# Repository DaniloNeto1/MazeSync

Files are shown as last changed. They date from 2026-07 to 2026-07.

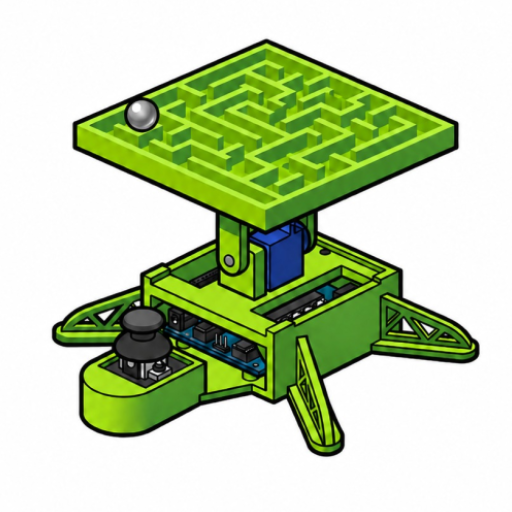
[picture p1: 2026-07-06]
app/src/main/app-playstore.png

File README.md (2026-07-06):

# 🕹️ MazeSync

Controle interativo em tempo real de um labirinto mecânico físico utilizando comunicação via rede sem fio entre um microcontrolador e um smartphone. 

Este repositório adota a arquitetura de **Monorepo**, contendo tanto o código embarcado (Hardware) quanto o aplicativo móvel (Software).

## 📐 Arquitetura do Sistema

O sistema é dividido em duas frentes que se comunicam via protocolo **UDP** em uma rede local (Access Point gerado pelo hardware), garantindo baixíssima latência (aprox. 15ms) para movimentação fluida.

1. **📱 App Android (Kotlin):** Lê os sensores de gravidade do smartphone utilizando a *Sensor API* nativa do Android SDK e atira pacotes UDP em uma *Thread* paralela (Background) contendo as coordenadas $X$ e $Y$.
2. **⚙️ Hardware (C++ / ESP32):** Microcontrolador recebe os pacotes de rede e traduz os ângulos em modulação PWM para controlar os micro-servos do labirinto. Também inclui lógica de interpolação para controle manual via Joystick analógico.

---

## 🛠️ Tecnologias Utilizadas

* **Linguagens:** Kotlin (App), C/C++ (Hardware)
* **Ambientes:** Android Studio, VS Code (PlatformIO)
* **Protocolo de Rede:** UDP (User Datagram Protocol) via Wi-Fi `802.11 b/g/n`
* **Hardware:** ESP32, Servo Motores (SG90), Módulo Joystick Analógico

---

## 🚀 HOW TO: Como executar o projeto

### Pré-requisitos
* **Android Studio** instalado para compilar o app.
* **VS Code** com a extensão **PlatformIO** para gravar o ESP32.

### Passo 1: Configurando o Hardware (ESP32)
1. Abra a pasta `Hardware-ESP32` no VS Code (PlatformIO).
2. Conecte o ESP32 ao computador via cabo USB.
3. Clique no ícone de **Upload** (seta para a direita) na barra inferior do PlatformIO para compilar e gravar o firmware na placa.
4. Após gravado, o ESP32 iniciará automaticamente uma rede Wi-Fi (Access Point).

### Passo 2: Configurando o Software (App Android)
1. Abra a pasta raiz do projeto Android no **Android Studio**.
2. Conecte seu smartphone ao computador via cabo USB (com o modo de depuração USB ativado) ou use um emulador.
3. Clique em **Run 'app'** (ícone de Play verde) na barra superior.
4. O aplicativo será instalado e aberto no seu dispositivo.

### Passo 3: Sincronizando (O Jogo)
1. No seu smartphone, vá nas configurações de Wi-Fi e conecte-se à rede gerada pelo ESP32 (ex: `MazeSync_AP`).
2. Abra o aplicativo MazeSync.
3. Incline o celular! O aplicativo fará a leitura da gravidade com um fator de ganho calibrado ($K = 7.0$) e os motores do labirinto responderão em tempo real respeitando a janela mecânica segura de 60° a 120°.

---

## 👨‍💻 Autor

**Danilo Pietrobon Neto** Engenharia de Computação - UTFPR
**Monica P. O. Mackert**  Engenharia de Computação - UTFPR

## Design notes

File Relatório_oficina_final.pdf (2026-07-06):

TRABALHO DE OFICINA DE INTEGRAÇÃO

## MazeSync: labirinto físico automatizado

DANILO PIETROBON NETO¹
MONICA PAULA OLIVEIRA MACKERT

2

PATO BRANCO - PR
JULHO/2026

1 Graduando em Engenharia de Computação pela UTFPR-PB.
email: danilopietrobon@alunos.utfpr.edu.br
2 | Graduanda | em | Engenharia | de | Computação | pela | UTFPR-PB.
email: monicamackert @alunos.utfpr.edu.br

RESUMO

Este artigo apresenta o desenvolvimento de um protótipo funcional de um labirinto físico automatizado controlado bilateralmente por meio de hardware dedicado e um aplicativo móvel personalizado. O sistema substitui as abordagens tradicionais baseadas em microcontroladores de arquitetura restrita pelo chip ESP32 de alto desempenho, programado no ecossistema PlatformIO. A inclinação do tabuleiro do labirinto é controlada por dois servo motores configurados nos eixos X e Y. O controle do sistema ocorre por meio de uma lógica de prioridades que integra um joystick analógico físico e um aplicativo Android desenvolvido em Kotlin no Android Studio. A comunicação sem fio é estabelecida configurando o ESP32 como Access Point (AP), recebendo dados de telemetria baseados nos sensores de gravidade e giroscópio do smartphone por meio do protocolo de transporte UDP (User Datagram Protocol). Os resultados obtidos demonstraram baixa latência e alta precisão na manipulação dinâmica e mecânica do tabuleiro, validando a integração de software móvel com sistemas embarcados de baixo custo.

Palavras-chave: ESP32. Android Studio. Kotlin. UDP. Giroscópio. Servomotores.

### 1. INTRODUÇÃO

O estudo e a implementação de sistemas ciber-físicos, o qual combina processamento computacional, redes de comunicação e processos mecânicos, representam um pilar essencial na formação em Engenharia de Computação. Jogos físicos clássicos de habilidade motora, como o labirinto de inclinação mecânica com esferas metálicas, oferecem um excelente modelo experimental para a aplicação desses conceitos. Tradicionalmente controlados de forma manual por manivelas, esses sistemas podem ser automatizados através de servomotores acionados por microcontroladores.

Contudo, muitos projetos acadêmicos utilizam plataformas limitadas em processamento e sem conectividade nativa, restringindo a experiência de controle a botões ou joysticks com fio. Este projeto propõe a modernização desse cenário através do desenvolvimento de um labirinto inteligente com controle bilateral: físico, via joystick analógico acoplado diretamente à base; e sem fio, utilizando os sensores de movimento internos de um dispositivo móvel.

O sistema foi reprojetado utilizando o SoC (System on Chip) ESP32, aproveitando sua capacidade de conectividade sem fio integrada e temporizadores robustos. A interface móvel foi desenvolvida em ambiente de produção moderno com a linguagem Kotlin. O objetivo central é analisar a viabilidade técnica e a eficiência de uma comunicação ponto a ponto de baixa latência em tempo real para controle mecânico de precisão, oferecendo uma alternativa robusta e de baixo custo para o ensino prático de sistemas integrados.

### 2. TRABALHOS RELACIONADOS

- Sistemas Embarcados com Controle por Fio: Diversas abordagens acadêmicas utilizam microcontroladores como o Arduino Uno acoplados a joysticks de potenciômetros bidirecionais (ex: KY023). Embora eficazes no controle mecânico básico, sofrem restrições severas de mobilidade espacial devido ao cabeamento físico estrutural.

- Aplicações de Telemetria com Protocolo TCP: Projetos que utilizam comunicação sem fio integrada via Wi-Fi frequentemente adotam o protocolo de transporte TCP para o envio de comandos de aplicativos móveis. Apesar de garantir a entrega confiável dos pacotes, a sobrecarga de controle (handshake, retransmissões) gera picos de latência que prejudicam o controle em tempo real de sistemas que necessitam de respostas instantâneas, como o equilíbrio de esferas.
- Sistemas Móveis de Captura Inercial: O uso de sensores internos de smartphones (como acelerômetros e giroscópios) é amplamente documentado em jogos digitais mobile. A adaptação desses dados brutos de hardware para a conversão mecânica de inclinação em dispositivos físicos externos de automação representa um campo de estudo dinâmico e em constante evolução no âmbito da Internet das Coisas (IoT).

### 3. REFERENCIAL TEÓRICO

Integração de Hardware e Software

A convergência entre hardware e software permite a criação de sistemas interativos onde informações do mundo físico são convertidas para dados digitais. No contexto do ecossistema MazeSync, essa integração possibilita a leitura de sensores inerciais e analógicos e a sua tradução em comandos angulares mecânicos.

Protocolo de Transporte UDP

Diferente do protocolo TCP, o UDP opera em modo não-orientado à conexão. Isso significa que os datagramas são enviados diretamente ao destino sem a necessidade de verificação de recebimento ou ordenação de pacotes. Essa ausência de overhead torna o UDP a escolha ideal para sistemas de controle contínuo, onde pacotes antigos perdem a validade e a taxa de atualização instantânea é prioritária.

Sensores Inerciais de Gravidade e Movimento

Dispositivos móveis modernos possuem IMUs (Units de Medição Inercial) integradas. O sensor de gravidade (Sensor. TYPE_GRAVITY) realiza uma filtragem de software dos componentes do acelerômetro, isolando a força da gravidade nos três eixos cartesianos (x, y, z). Ao inclinar o celular, os valores gerados representam a aceleração em m/s² aplicada sobre cada eixo coordenado.

### 4. METODOLOGIA

Arquitetura Estrutural do Hardware
O protótipo consiste em uma estrutura física composta por uma base estável, um braço mecânico de suporte articulado em dois eixos e um tabuleiro superior dotado de um labirinto impresso em 3D. A movimentação física é executada por dois servo motores micro (SG90) alimentados por modulação por largura de pulso (PWM) gerada de forma independente através dos timers nativos do ESP32 via biblioteca ESP32Servo. O código de controle foi estruturado com base em uma máquina de estados de prioridades bem definidas rodando em um loop cíclico de 15 ms.

Prioridade 1 - Botão SW: O pino digital PIN_JOY_SW configurado com resistor pull-up interno monitora continuamente o botão do joystick. Se o botão for pressionado (LOW), o sistema executa a função resetarCentro(), forçando os servos a ficarem nivelados.

Prioridade 2 - Controle Físico Dinâmico: Se o joystick for retirado de sua zona morta (JOY_DEADZONE = 150), os sinais analógicos das portas PIN_JOY_X e PIN_JOY_Y são convertidos pelo ADC interno (0 a 4095). É calculado um

incremento angular dinâmico (variando de 0. 2 a 1. 5 graus), que é somado à posição atual dos servos. Enquanto o joystick estiver em movimento, os comandos sem fio são ignorados.

Prioridade 3 - Controle Móvel: Caso o joystick permaneça estático no centro, o ESP32 passa a processar as requisições de rede. Ele varre o buffer do socket de escuta UDP (udpPort = 12345). Se houver pacotes, os dados textuais são processados via função sscanf() para extrair os novos ângulos absolutos enviados pelo aplicativo Android.

Para garantir a integridade dos servos e das articulações impressas, todos os ângulos calculados passam obrigatoriamente pela função limitarAngulo(), que restringe fisicamente o curso de movimento entre a faixa de segurança de 58 a 118 graus.

Para mitigar desvios de montagem, foram criadas as variáveis SERVO_CENTER_X e SERVO_CENTER_Y, permitindo calibrar de forma independente o nivelamento de cada eixo em 88 graus para compensar os desalinhamentos físicos da estrutura.

Conectividade de Rede e Configuração do Access Point (AP)

Para garantir independência de redes locais e roteadores externos, o ESP32 é inicializado programaticamente no modo Access Point (AP) de forma isolada. O firmware define uma rede local Wi-Fi restrita com o SSID "MazeSync − ESP32" protegida por criptografia WPA2. O dispositivo embarcado define para si um IP estático fixo (192.168.4.1) e inicializa o servidor UDP na porta 12345, aguardando pacotes de dados originados do cliente conectado.

Desenvolvimento do Aplicativo Android

O aplicativo de controle móvel foi desenvolvido em ambiente nativo Android Studio utilizando a linguagem Kotlin com suporte à arquitetura moderna de telas cheias (enableEdgeToEdge). O fluxo de execução do software consiste na seguinte rotina:

Gerenciamento de Sensores: Durante o ciclo de atividade em primeiro plano

(onResume), o aplicativo registra um ouvinte (SensorEventListener) associado ao Sensor. TYPE_GRAVITY configurado com taxa de amostragem

otimizada para jogos eletrônicos (SENSOR_DELAY_GAME).

Processamento de Dados Inerciais: No evento onSensorCℎanged, os valores brutos de gravidade dos eixos X e Y são capturados. O aplicativo aplica um fator de escala linear (7. 0) adicionado ao centro trigonométrico de

90 graus: anguloX = 90(gx * 7, 0).

Os resultados finais são sanitizados utilizando a função de extensão . coerceIn(60, 120), garantindo a conformidade lógica com os limites mecânicos do hardware.

Transmissão Assíncrona via Rede: Para evitar o congelamento da interface gráfica (UI Tℎread) do usuário, sempre que uma alteração angular é detectada, uma linha de execução paralela (tℎread) é gerada. O payload é estruturado como uma String otimizada no formato simples "X,Y", convertida em um array de bytes UTF-8 e encapsulada em um pacote DatagramPacket disparado via DatagramSocket diretamente para o endereço IP do destino (192.168.4.1:12345).

### 5. RESULTADOS E DISCUSSÕES

Resultados do Sistema Embarcado e Hardware

O ecossistema montado com o PlatformIO garantiu a portabilidade exata e estabilidade das diretivas de compilação do chip esp32doit-devkit-v1. O controle do pulso PWM via hardware utilizando os timers internos do ESP32 eliminou por completo trepidações mecânicas comuns causadas por ruídos de amostragem. A filtragem de software baseada em zonas mortas no código do ADC preveniu movimentos falsos indesejados originados do joystick físico.

Desempenho do Aplicativo Móvel e Comunicação UDP

O sensor de gravidade implementado no Android Studio mostrou-se extremamente responsivo a mudanças sutis de orientação física do smartphone. A interface gráfica do aplicativo atualizou de forma contínua e assíncrona as coordenadas processadas, exibindo na tela os ângulos dinâmicos de transmissão de forma clara.

O uso do protocolo UDP sem conexão eliminou os atrasos severos observados em sistemas semelhantes operando em protocolos orientados a fluxo. A String estruturada separada por vírgulas representou uma carga útil de rede insignificante, permitindo que o processamento interno do ESP32 via sscanf realizasse a extração das coordenadas em microsegundos, resultando em um controle mecânico altamente intuitivo e em tempo real.

Prioridade de Controle

Os testes práticos comprovaram a integridade e eficácia da arquitetura modular de prioridades. Quando o usuário inclinava o celular (transmitindo pacotes contínuos por Wi-Fi) e realizava um toque manual no joystick, o firmware interrompia o processamento da rede imediatamente para obedecer ao periférico físico, retornando ao controle sem fio no exato momento em que o joystick era solto. O acionamento do botão físico de reset interrompeu o fluxo de execução global de forma segura, garantindo o retorno da esfera metálica ao centro do tabuleiro sempre que necessário.

### 5.1 Demonstração Prática e Resultados Visuais

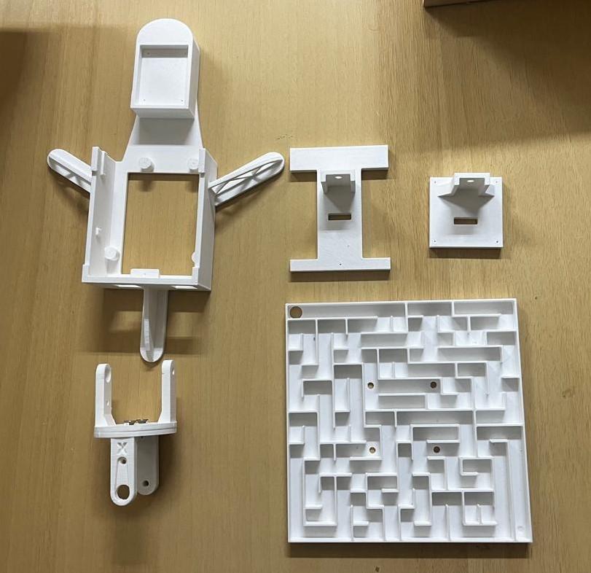
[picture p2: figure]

Figura 1: Estrutura física 3D. Fonte: Autoria própria.

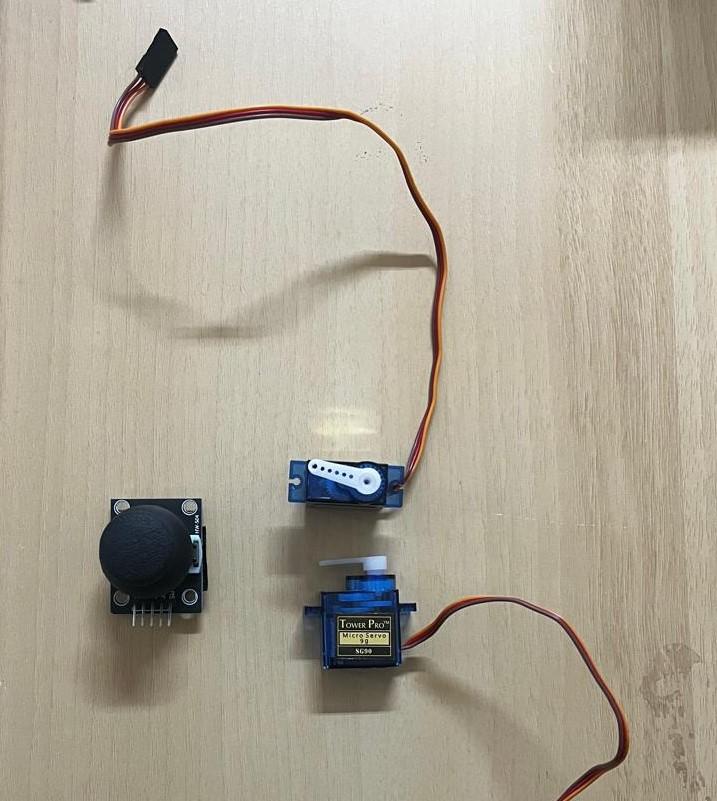
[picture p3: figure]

Figura 2: Servo motor SG90 e Joystick KY023 Fonte: Autoria própria.

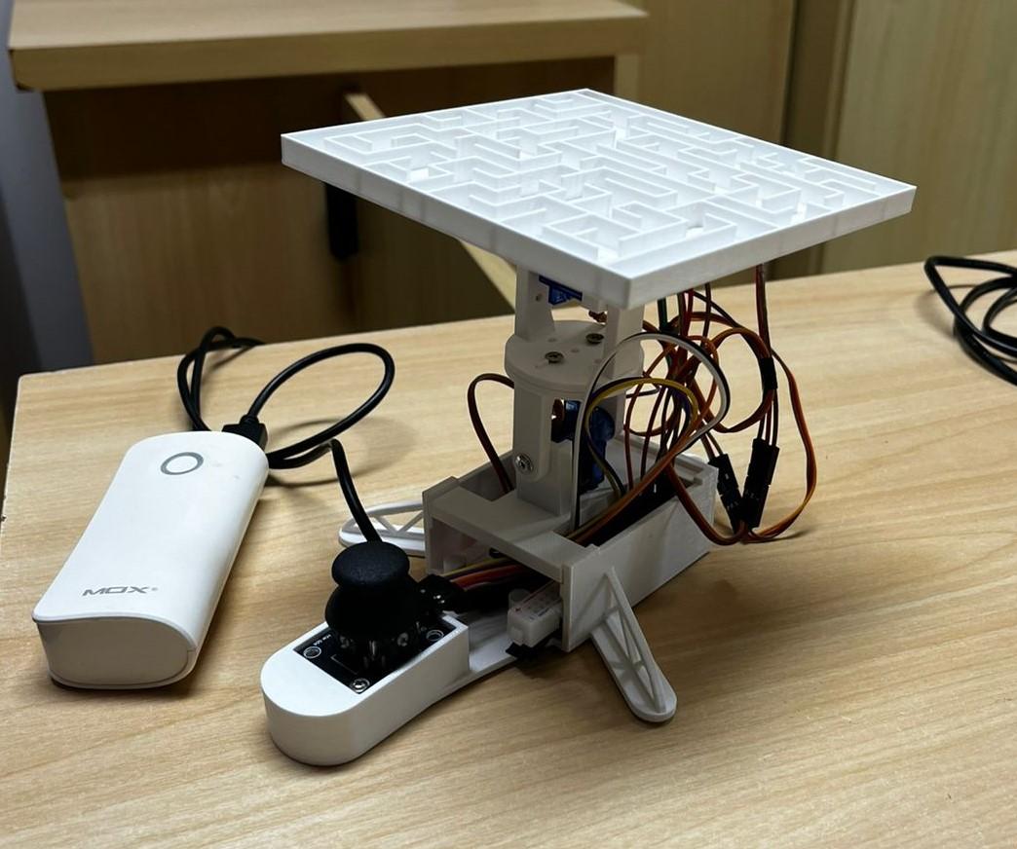
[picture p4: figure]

Figura 3: Visual final do labirinto MazeSync. Fonte: Autoria própria.

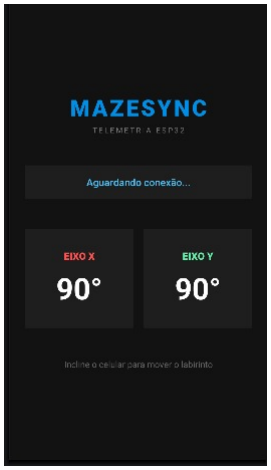
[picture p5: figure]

Figura 4: Interface do aplicativo Android. Fonte: Autoria própria.

### 6. CONSIDERAÇÕES FINAIS

O projeto do sistema de controle dinâmico bilateral de labirinto físico atingiu com sucesso os objetivos estabelecidos na disciplina de Oficina de Integração. A substituição do hardware básico tradicional e de metodologias rudimentares de controle por uma arquitetura combinando o poder computacional do chip ESP32 e o desenvolvimento mobile em Kotlin se provou uma escolha tecnológica superior.
A implementação da rede ponto a ponto local em modo Access Point e o uso estruturado de conexões e soquetes de transporte UDP provaram que é possível desenvolver soluções de controle embarcado sem fio estáveis e rápidas, sem a dependência de infraestruturas locais complexas de rede.
Para melhorias e trabalhos futuros, sugere-se a adição de sensores ópticos nas paredes do labirinto impresso em 3D para cronometrar as partidas, transmitindo o tempo de resolução final de volta para o aplicativo Android a fim de gerar um painel histórico de recordes locais dos usuários.

### 7. REFERÊNCIAS

ANDROID DEVELOPERS. Sensors Overview. Android Open Source Project, 2026. Disponível em:
https://developer.android.com/guide/topics/sensors/sensors_overview. Acesso em: 06 jul. 2026.

ARDUINO. Arduino Core AVR: Arduino.h. versão 1.8.6. GitHub, 2024. Disponível em: https://github.com/arduino/ArduinoCore-avr/blob/master/cores/arduino/Arduino.
h. (https://github.com/arduino/ArduinoCore-avr/blob/master/cores/arduino/Arduino.h) Acesso em: 06 jul. 2026.

ESPRESSIF SYSTEMS. Arduino-ESP32 WiFi Library: WiFi.h. GitHub, 2025. Disponível em:
https://github.com/espressif/arduino-esp32/blob/master/libraries/WiFi/src/WiFi.h. Acesso em: 06 jul. 2026.

ESPRESSIF SYSTEMS. Arduino-ESP32 WiFi Library: WiFiUdp.h. GitHub, 2025. Disponível em:
https://github.com/espressif/arduino-esp32/blob/master/libraries/WiFi/src/WiFiU dp.h. (https://github.com/espressif/arduino-esp32/blob/master/libraries/WiFi/src/WiFiUdp.h) Acesso em: 06 jul. 2026.

ESPRESSIF SYSTEMS. ESP-IDF Programming Guide. v5.3. Espressif Systems Documentation, 2026. Disponível em: https://docs.espressif.com/projects/esp-idf/en/latest/esp32/. Acesso em: 06 jul. 2026.

KADNING, J. ESP32Servo Library: ESP32_Servo.h. versão 3.0. GitHub, 2024. Disponível em:
https://github.com/jkb-git/ESP32Servo/blob/master/src/ESP32_Servo.h. (https://www.google.com/search) Acesso em: 06 jul. 2026.

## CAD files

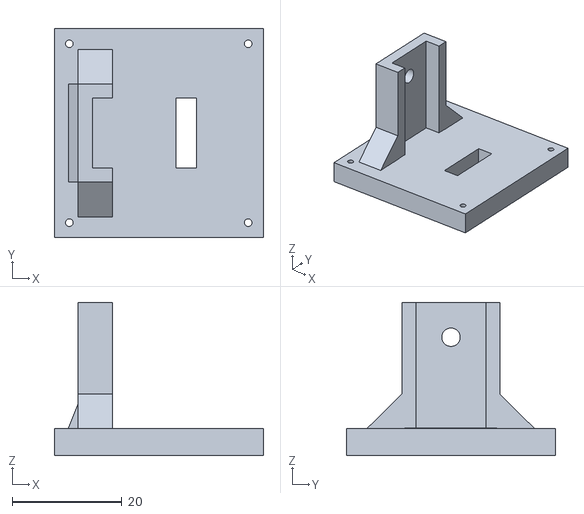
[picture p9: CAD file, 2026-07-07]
3D-Labirinto/Maze+Robot+Maze+Mount.stl
38.1 x 38.1 x 28.0

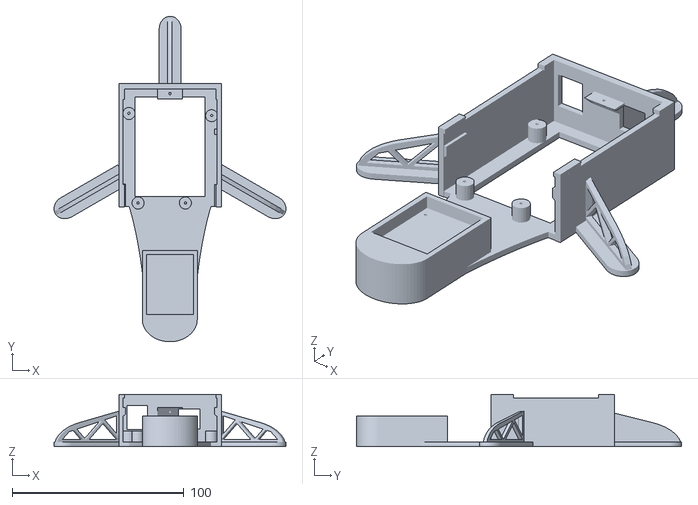
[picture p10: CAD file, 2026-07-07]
3D-Labirinto/Maze+Robot+Base.stl
135.0 x 189.4 x 30.3

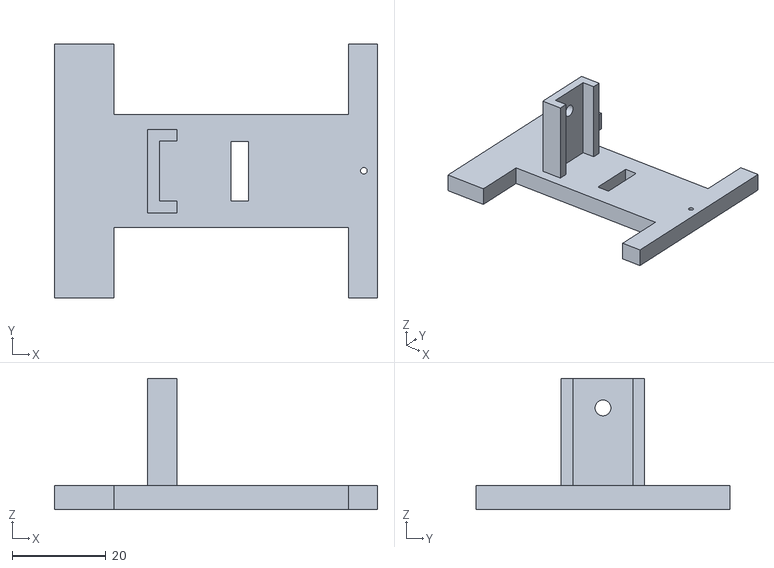
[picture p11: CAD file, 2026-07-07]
3D-Labirinto/Maze+Robot+Base+Cover.stl
68.7 x 54.1 x 27.9

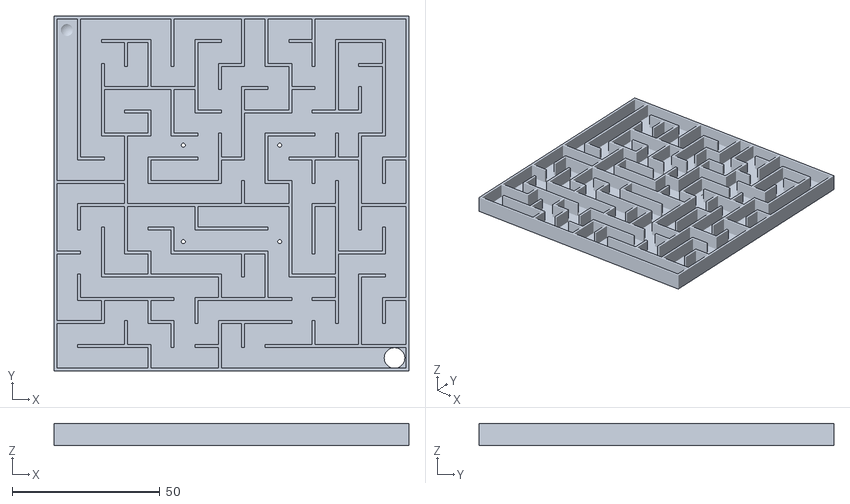
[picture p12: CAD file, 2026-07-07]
3D-Labirinto/Maze+Robot+Maze.stl
120.0 x 120.0 x 7.50

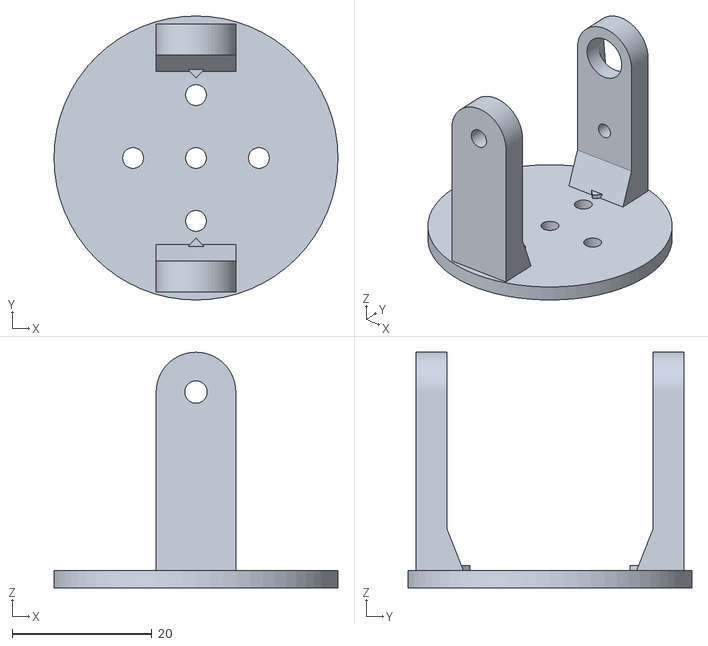
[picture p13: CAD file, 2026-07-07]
3D-Labirinto/Maze+Robot+X+Gimbal.stl
40.6 x 40.6 x 33.7

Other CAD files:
3D-Labirinto/Maze+Robot+Y+Gimbal.stl

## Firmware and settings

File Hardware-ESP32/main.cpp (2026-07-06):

//bibliotecas
#include <Arduino.h> //para uso de funçoes como pinMode, delay...
#include <ESP32Servo.h> //para o controle dos servos com ESP32
#include <WiFi.h> //para conexão WiFi do ESP
#include <WiFiUdp.h> //para comunicaçao UDP com WiFi

// O ESP32 agora cria a própria rede Wi-Fi no modo Access Point.
// O Android deve se conectar nessa rede e enviar UDP para 192.168.4.1:12345.
const char* AP_SSID = "MazeSync-ESP32";
const char* AP_PASSWORD = "12345678";

IPAddress AP_LOCAL_IP(192, 168, 4, 1);
IPAddress AP_GATEWAY(192, 168, 4, 1);
IPAddress AP_SUBNET(255, 255, 255, 0);

//porta UDP para conexão do celular com ESP
const unsigned int udpPort=12345;

WiFiUDP udp; //gerenciador da comunicação UDP
char buffer[255]; //armazena a mensagem recebida do celular

//pinagem
//pinos para LEITURA do joystick. Tensão convertida em um valor de 0 a 4095
#define PIN_JOY_X 34 //eixo X do joy (esquerda direita)
#define PIN_JOY_Y 35 //eixo Y do joy (frente/tras)
#define PIN_JOY_SW 32 //botão do joy que quando pressionado tabuleiro fica em 90 graus (low)

//pinos de SAIDA para os servos (PWM)
#define PIN_SERVO_X 18 // servo que vai inclinar o labirinto em X
#define PIN_SERVO_Y 19 //servo que vai inclinar o labirinto em Y

//configuração dos servos 
//definição de angulos limites 
//#define SERVO_CENTER 70 //posição central, em 90 graus nivelado
#define SERVO_CENTER_X  88   // ajuste este se o eixo X também estiver torto
#define SERVO_CENTER_Y  88   // ALTERE ESTE — diminua se inclina para frente, aumente se para trá

#define SERVO_MIN 58 //angulo minimo (inclinação maxima -)
#define SERVO_MAX 118 //angulo maximo (maximo em +) 

//configuração do joystick
//gera valores de 0 a 4095, o centro é 1950
#define JOY_CENTER 1950 //valor do ADC quando joystick parado
#define JOY_DEADZONE 150 //faz com que o labirinto sofra com ruidos. Reage se o valor sair da faixa de 1800 a 2100

//configuração do incremento
#define INCREMENTO_MAX 1.5f //angulo muda 2.5 graus por ciclo (maximo)
#define INCREMENTO_MIN 0.2f //muda 0.3 por ciclo (saindo da deadzone)
#define LOOP_DELAY_MS 15 //loop roda a cada 15milisegundos

//variaveis globais/prototipos
Servo servoX; //obejto que representa e controla o servo do eixo X
Servo servoY; //obejto que representa e controla o servo do eixo Y

//angulos atuais do servo. Saem do centro
float anguloX = SERVO_CENTER_X;
float anguloY = SERVO_CENTER_Y;

//prototipos de funcoes 
float calcularIncremento(int valorADC); 
float limitarAngulo(float angulo);
void resetarCentro();
void iniciarWifiAccessPoint();

//setup
void setup(){
  Serial.begin(115200); //inicio da comunicação serial

  //configuracao do pino do botao como ENTRADA. Resistor pull-up (padrao é high e quando pressionado vai para low)
  pinMode(PIN_JOY_SW, INPUT_PULLUP);

  //configuração de timers para gerar o pwm dos servos. Um timer para cada servo,
  ESP32PWM::allocateTimer(0);
  ESP32PWM::allocateTimer(1);

  //configuracao dos servos
  servoX.setPeriodHertz(50); //padrao 
  servoY.setPeriodHertz(50);
  servoX.attach(PIN_SERVO_X, 500, 2400); //
  servoY.attach(PIN_SERVO_Y, 500, 2400);

  resetarCentro(); //os dois servos no centro
  delay(500); //espera 500 milisegundos para o servo chegar ao centro

  iniciarWifiAccessPoint();
  udp.begin(udpPort);

  Serial.println("UDP iniciado.");
  Serial.print("Porta UDP: ");
  Serial.println(udpPort);
}

//loop
void loop(){
  //botao pressionado entao centraliza. Prioridade 1
  if(digitalRead(PIN_JOY_SW)==LOW){
    resetarCentro();
    delay(300); //tratamento para nao registrar o botao 2 vezes
    return; //nao faz o resto do loop e comeca no outro ciclo
  }

  //leitura do joy, prioridade 2
  int leituraX=analogRead(PIN_JOY_X); 
  int leituraY=analogRead(PIN_JOY_Y); 

  //calculo de mudança do angulo baseado na posição do joy
  float deltaX=calcularIncremento(leituraX); 
  float deltaY=calcularIncremento(leituraY); 

  //se joy se moveu (delta diferente de 0), contole com joy
  if(abs(deltaX)>0.01f||abs(deltaY)>0.01f){
    anguloX=limitarAngulo(anguloX+deltaX); //soma incremento do angulo atual
    anguloY=limitarAngulo(anguloY+deltaY);
  }
  else{ //joy parado controle via celular. Prioridade 3
    int packetSize=udp.parsePacket(); //ve se chegou mensagem
    if(packetSize){
      int len=udp.read(buffer, sizeof(buffer)-1); //le a mensagem do buffer com espaço para ' '
      if(len>0){
        buffer[len]=0;
      }

      int novoX, novoY;
      if(sscanf(buffer, "%d,%d", &novoX, &novoY)==2){
        anguloX=limitarAngulo((float)novoX);
        anguloY=limitarAngulo((float)novoY);

        Serial.print("Recebido do Android: ");
        Serial.println(buffer);
      }
    }
  }

  //envia angulos calculados para os servos
  servoX.write((int)anguloX);
  servoY.write((int)anguloY);

  //debug no Serial Monitor
  Serial.printf("JoyX: %4d | JoyY: %4d | ServX: %5.1f | ServY: %5.1f", leituraX, leituraY, anguloX, anguloY);

  delay(LOOP_DELAY_MS);
}

void iniciarWifiAccessPoint(){
  WiFi.disconnect(true); //limpa configurações antigas da memória
  WiFi.mode(WIFI_AP); //configuracao do ESP32 para operar no modo Access Point

  //aplica configuracoes de IP fixo, Gateway e Máscara
  if(!WiFi.softAPConfig(AP_LOCAL_IP, AP_GATEWAY, AP_SUBNET)){
    Serial.println("Falha ao configurar IP fixo do Access Point."); //aviso caso falha
  }

  //inicializa a rede Wi-Fi local gerando o SSID (nome) e a senha protegida por WPA2
  bool apOk = WiFi.softAP(AP_SSID, AP_PASSWORD);

  //validacao da rede
  if(apOk){
    Serial.println("Access Point iniciado.");
    Serial.print("Rede Wi-Fi: ");
    Serial.println(AP_SSID);
    Serial.print("Senha: ");
    Serial.println(AP_PASSWORD);
    Serial.print("IP do ESP32: ");
    Serial.println(WiFi.softAPIP());
  }
  else{
    Serial.println("ERRO: falha ao iniciar Access Point do ESP32."); //aviso caso falha
  }
}

float calcularIncremento(int valorADC) {
  int desvio=valorADC-JOY_CENTER; //distância entre leitura atual do ADC (0-4095) e o centro (1950)

  //quando o valor absoluto do desvio for menor que a zona morta (150) o joystick nao move
  if (abs(desvio)<JOY_DEADZONE){
    return 0.0f;
  }
  
  float desvioUtil=abs(desvio)-JOY_DEADZONE; //remove a regiao da zona morta do desvio para obter o deslocamento pedido pelo usuário
  float desvioMax=(float)(JOY_CENTER-JOY_DEADZONE); //desvio maximo possivel a partir do centro
  float normalizado=constrain(desvioUtil/desvioMax, 0.0f, 1.0f); //normaliza o desvio em uma escala de 0.0 (início do movimento) a 1.0 (fim do movimento)

  float incremento=INCREMENTO_MIN+normalizado*(INCREMENTO_MAX-INCREMENTO_MIN); //velocidade do incremento angular

  if (desvio>0){
    return incremento; //se o desvio foi positivo joystick para a direita/frente
  } else{
    return -incremento; //senao joystick para a esquerda/trás
  }
}

float limitarAngulo(float angulo) {
  if (angulo<SERVO_MIN){
    return (float)SERVO_MIN;
  }
  
  if (angulo>SERVO_MAX){
    return (float)SERVO_MAX;
  }
 
  return angulo;
}

void resetarCentro() {
  anguloX = SERVO_CENTER_X;  // era SERVO_CENTER (90°)
  anguloY = SERVO_CENTER_Y;  // era SERVO_CENTER (90°)
  servoX.write(SERVO_CENTER_X);  // era SERVO_CENTER (90°)
  servoY.write(SERVO_CENTER_Y);  // era SERVO_CENTER (90°)
}

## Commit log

2026-07-06 feat: Unificando projeto Android e ESP32 (Monorepo)
    [app.xml, app_round.xml]
2026-07-06 docs: Adicionando relatório final da Oficina de Integração
2026-07-07 docs: Adicionando 3D-Labirinto
    [Maze+Robot+Base+Cover.stl, Maze+Robot+Base.stl, Maze+Robot+Maze+Mount.stl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]
